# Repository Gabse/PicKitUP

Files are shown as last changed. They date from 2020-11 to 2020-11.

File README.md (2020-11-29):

# PicKitUP

AVR & SAM Adapter for Pickit4/SNAP 

 
=
Just a simple adapter board to connect most common AVR and SAM ICSP Ports to the Microchip Pickit4/SNAP Programmer

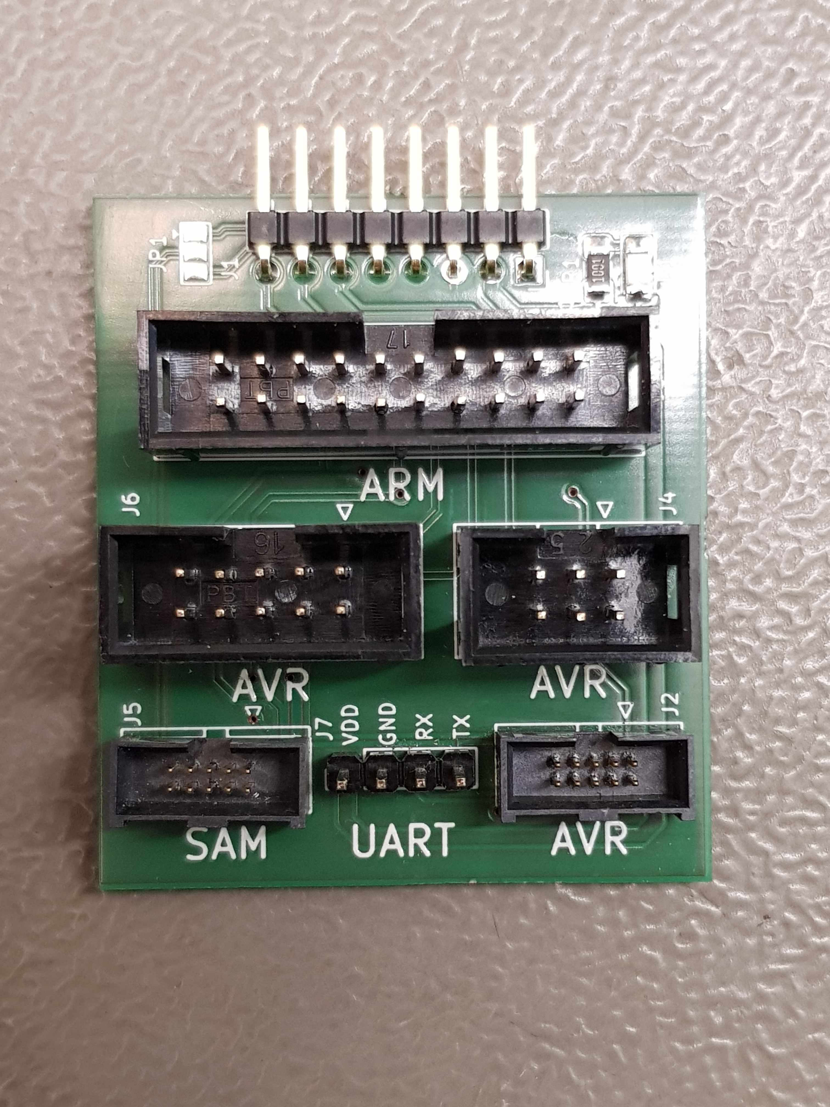
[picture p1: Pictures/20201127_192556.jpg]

=
If you Like this Project you can donate to the KiCad Project :

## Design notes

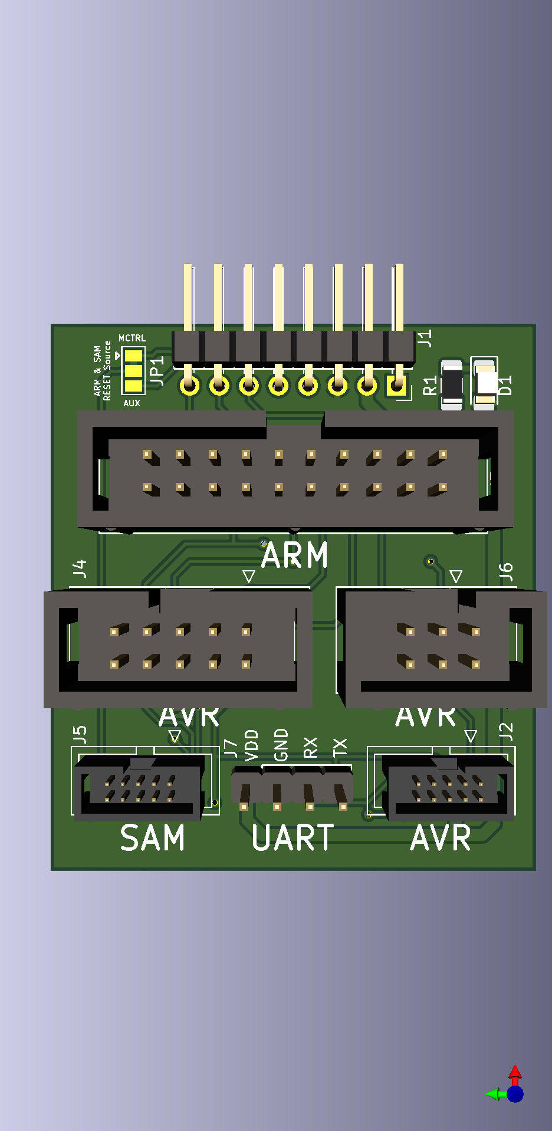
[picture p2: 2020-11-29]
Pictures/Render_Front.png

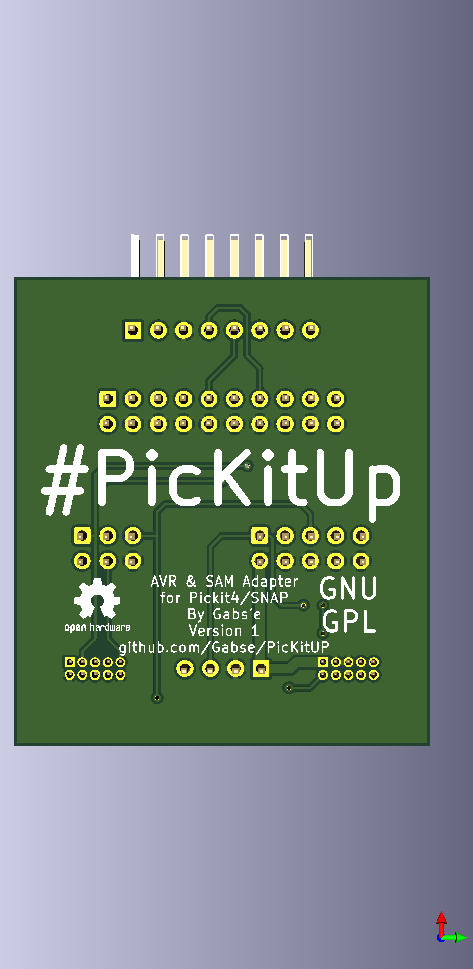
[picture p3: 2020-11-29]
Pictures/Render_Back.png

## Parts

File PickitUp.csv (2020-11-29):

Reference | Quantity | Value | Footprint | Datasheet | Manufacturer | Manufacturer Part Number | Order Code | Source
D1 | 1 | LED | LED_SMD:LED_1206_3216Metric_Pad1.42x1.75mm_HandSolder | https://www.we-online.de/katalog/datasheet/150120SS75000.pdf | Wurth Elektronik | 150120SS75000 | 2322087 | Farnell
J1 | 1 | PicKit_Connector | PickitUp:PinHeader_1x08_P2.54mm_Horizontal_Inverse | https://cdn.amphenol-icc.com/media/wysiwyg/files/drawing/68015.pdf | Amphenol FCI | 68016-208HLF | 2892394 | Farnell
J2 | 1 | AVR-JTAG-10 | PickitUp:SHF-105-01-L-D-TH | http://suddendocs.samtec.com/prints/shf-1xx-01-x-d-xx-xx-mkt.pdf | Samtec | SHF-105-01-L-D-TH | 2308450 | Farnell
J3 | 1 | ARM_JTAG_20 | Connector_IDC:IDC-Header_2x10_P2.54mm_Vertical | https://www.we-online.com/catalog/datasheet/61200621621.pdf | Wurth Elektronik | 61202021621 | 1642021 | Farnell
J4 | 1 | AVR-ISP-10 | Connector_IDC:IDC-Header_2x05_P2.54mm_Vertical | https://www.we-online.com/catalog/datasheet/61201021621.pdf | Wurth Elektronik | 61201021621 | 1642019 | Farnell
J5 | 1 | ARM_JTAG_10 | PickitUp:SHF-105-01-L-D-TH | http://suddendocs.samtec.com/prints/shf-1xx-01-x-d-xx-xx-mkt.pdf | Samtec | SHF-105-01-L-D-TH | 2308450 | Farnell
J6 | 1 | AVR-ISP-6 | Connector_IDC:IDC-Header_2x03_P2.54mm_Vertical | https://www.we-online.com/catalog/datasheet/61200621621.pdf | Wurth Elektronik | 61200621621 | 2356251 | Farnell
J7 | 1 | UART | Connector_PinHeader_2.54mm:PinHeader_1x04_P2.54mm_Vertical | https://www.we-online.com/catalog/datasheet/61300411121.pdf | Wurth Elektronik | 61300411121 | 2356155 | Farnell
JP1 | 1 | RESET | Jumper:SolderJumper-3_P1.3mm_Bridged12_Pad1.0x1.5mm | ~
R1 | 1 | 1k | Resistor_SMD:R_1206_3216Metric_Pad1.42x1.75mm_HandSolder | https://www.vishay.com/docs/20035/dcrcwe3.pdf | Vishay | CRCW12061K00FKEBC | 71-CRCW12061K00FKEBC | Farnell

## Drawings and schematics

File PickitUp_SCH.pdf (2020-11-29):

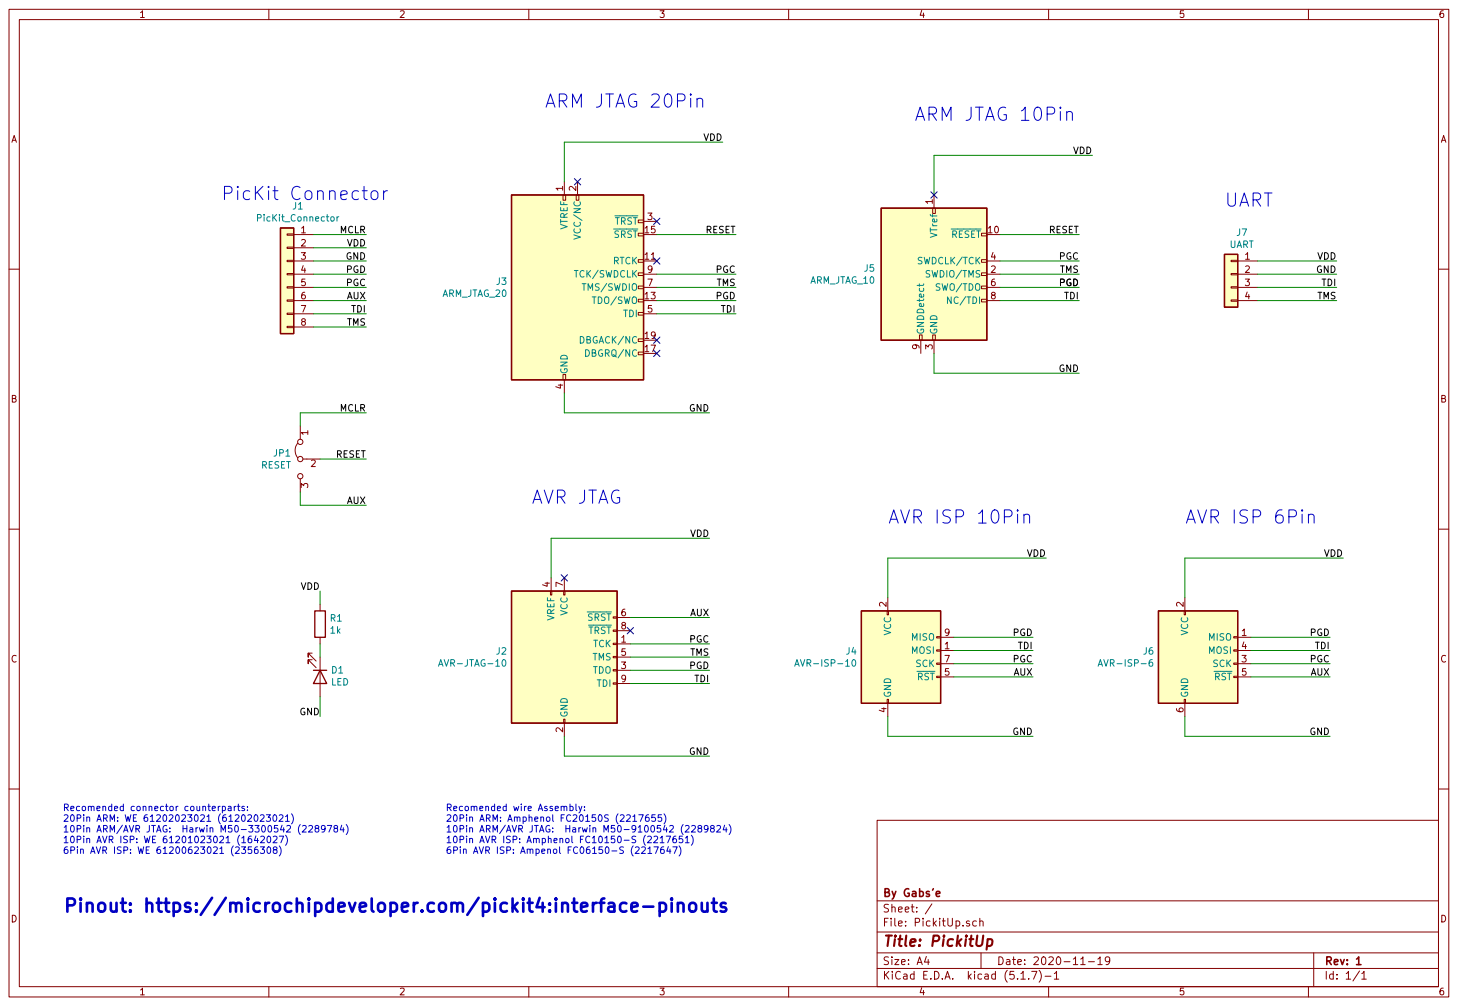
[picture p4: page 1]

1 RTCK 11 TDO/SWO 13 SRST 15 DBGRQ/NC 17 DBGACK/NC 19 VCC/NC
J7 UART VTREF

3 SWDCLK/TCK 4 SWO/TDO 6 NC/TDI 8 GNDDetect 9

4 TDI 5 TMS/SWDIO 7 TCK/SWDCLK 9

2 SCK 3 MOSI 4 RST 5 GND

Recomended connector counterparts:
20Pin ARM: WE 61202023021 (61202023021)
10Pin ARM/AVR JTAG: Harwin M50-3300542 (2289784)
10Pin AVR ISP: WE 61201023021 (1642027)
6Pin AVR ISP: WE 61200623021 (2356308)

Recomended wire Assembly:
20Pin ARM: Amphenol FC20150S (2217655)
10Pin ARM/AVR JTAG: Harwin M50-9100542 (2289824)
10Pin AVR ISP: Amphenol FC10150-S (2217651)
6Pin AVR ISP: Ampenol FC06150-S (2217647)

File: PickitUp.sch Sheet: / By Gabs'e

Pinout: https://microchipdeveloper.com/pickit4:interface-pinouts

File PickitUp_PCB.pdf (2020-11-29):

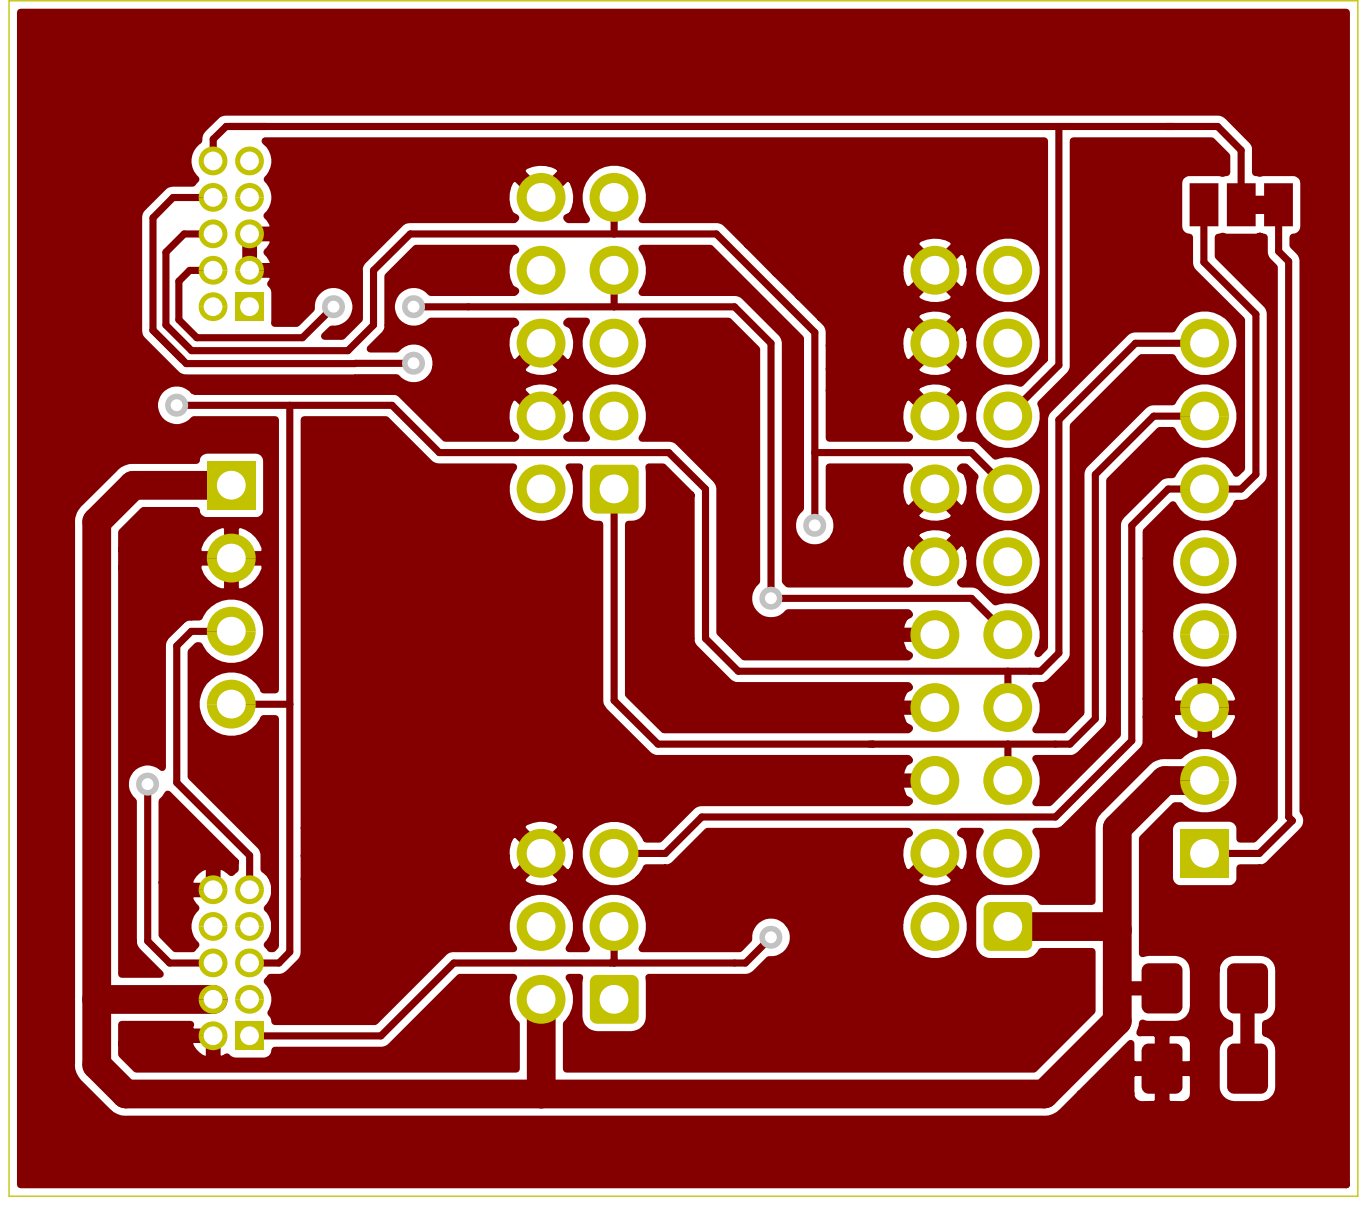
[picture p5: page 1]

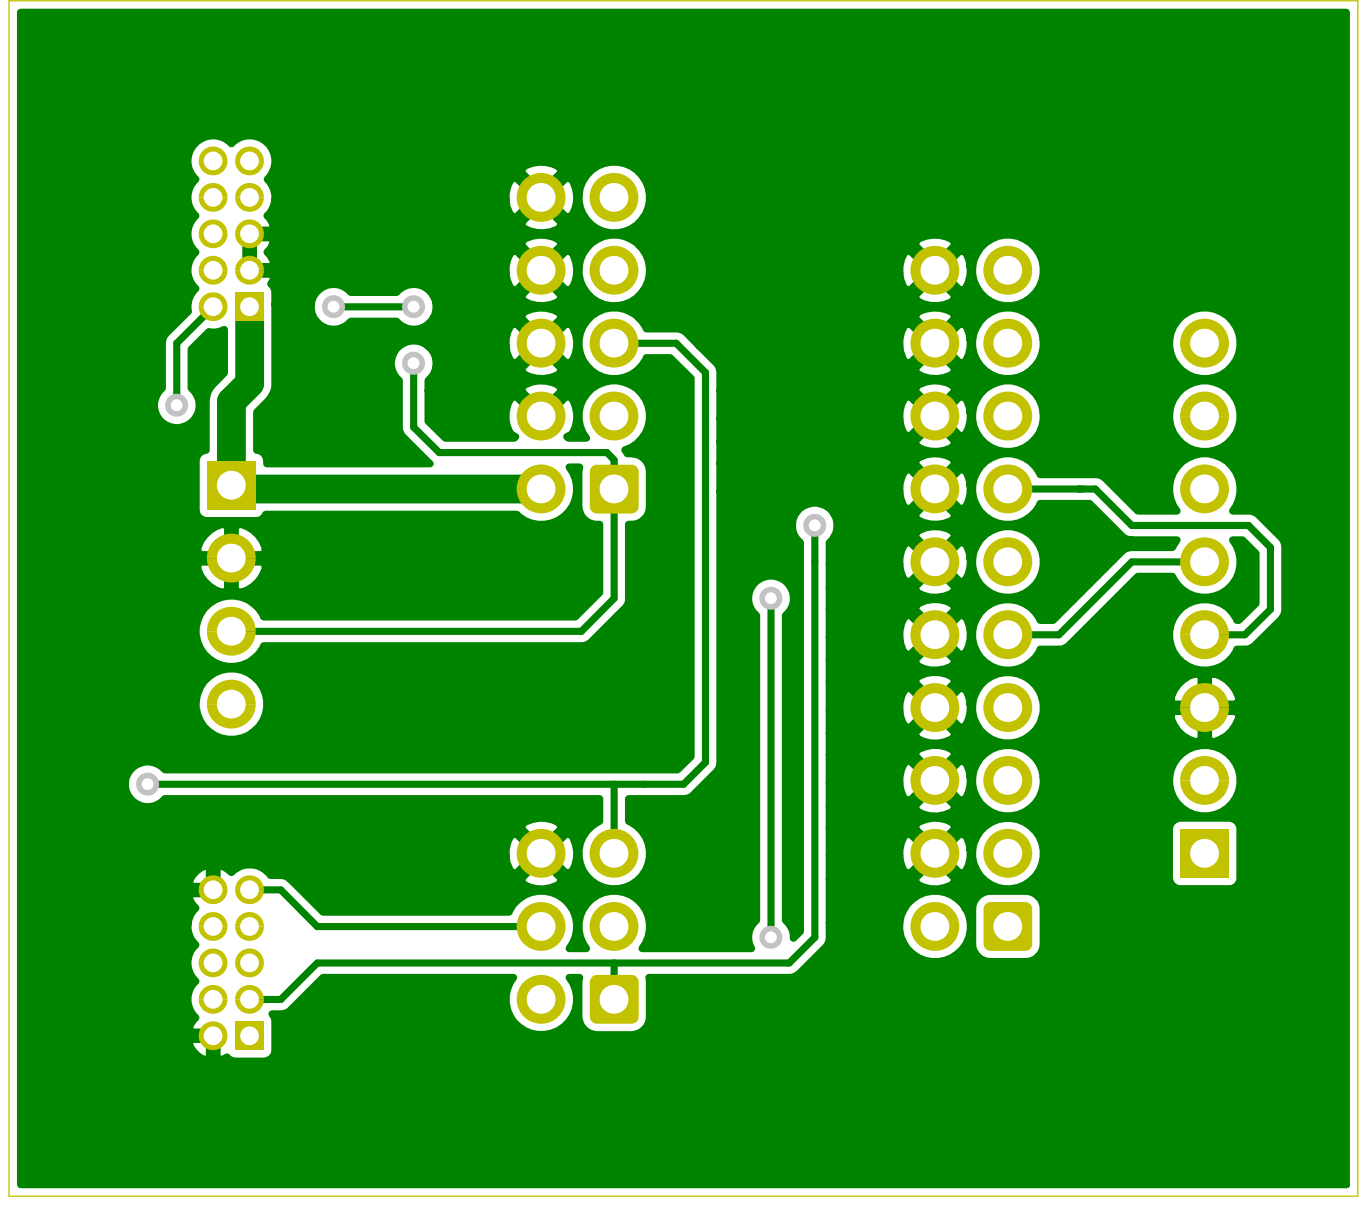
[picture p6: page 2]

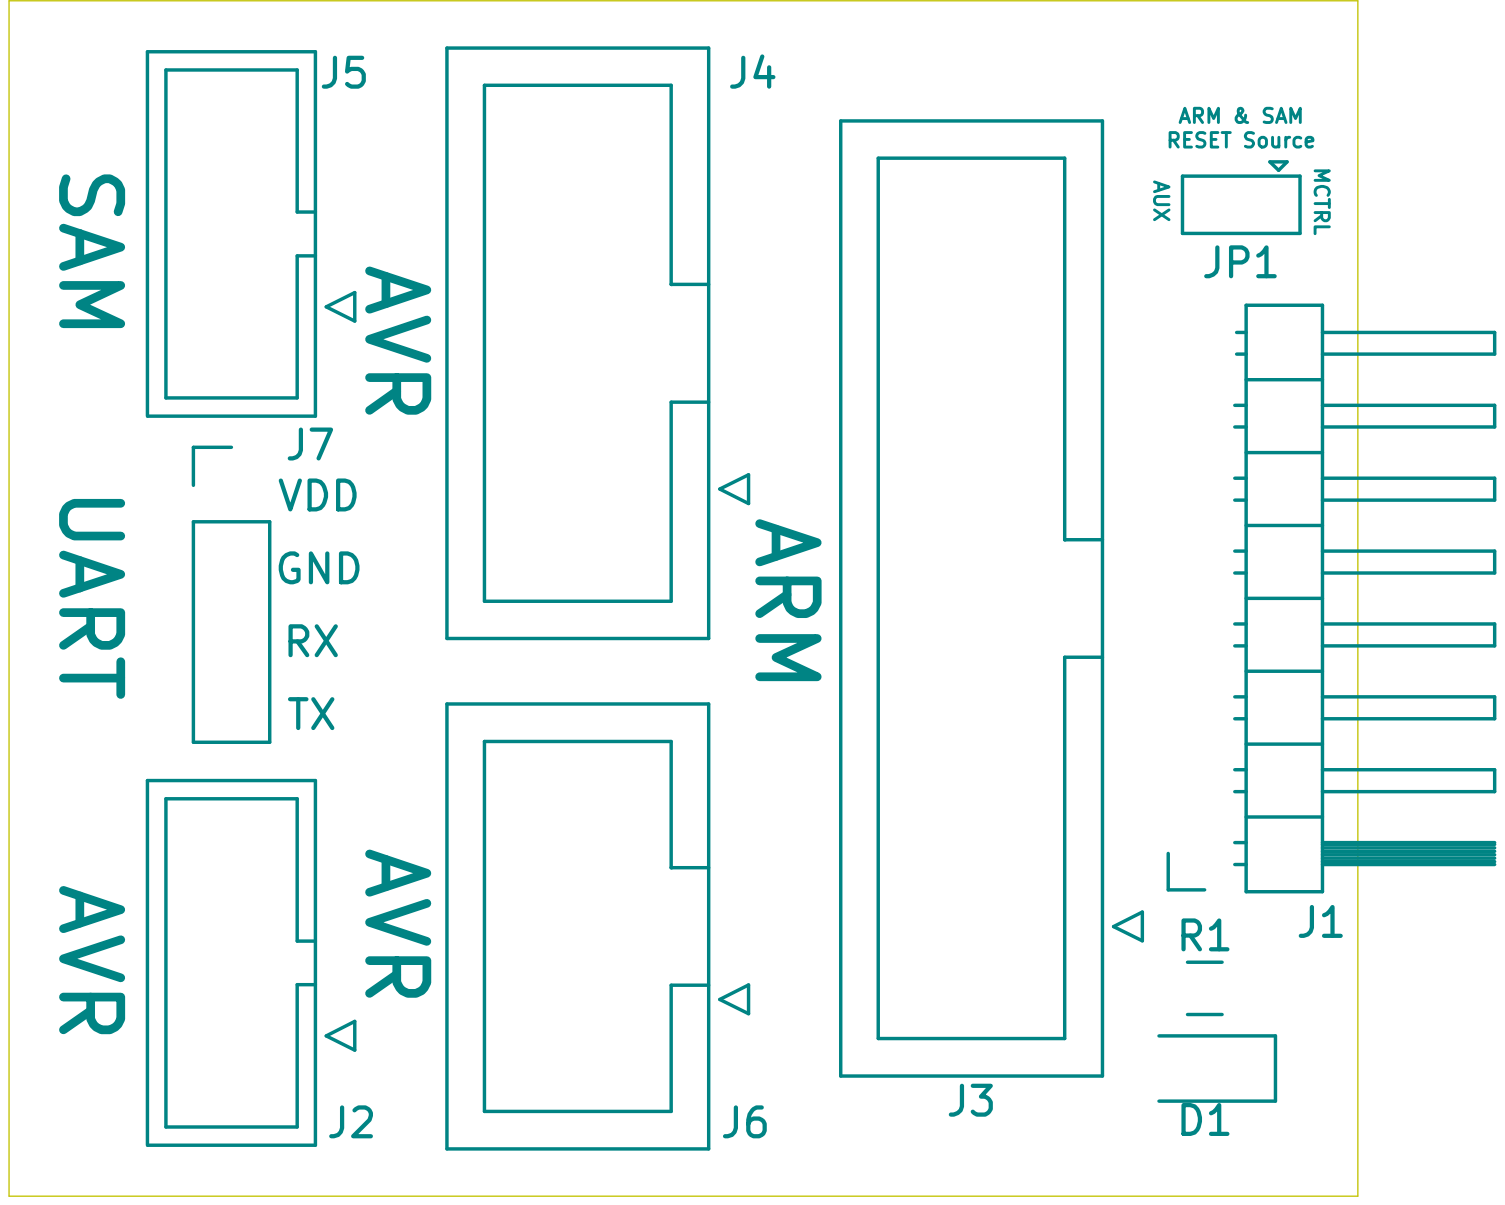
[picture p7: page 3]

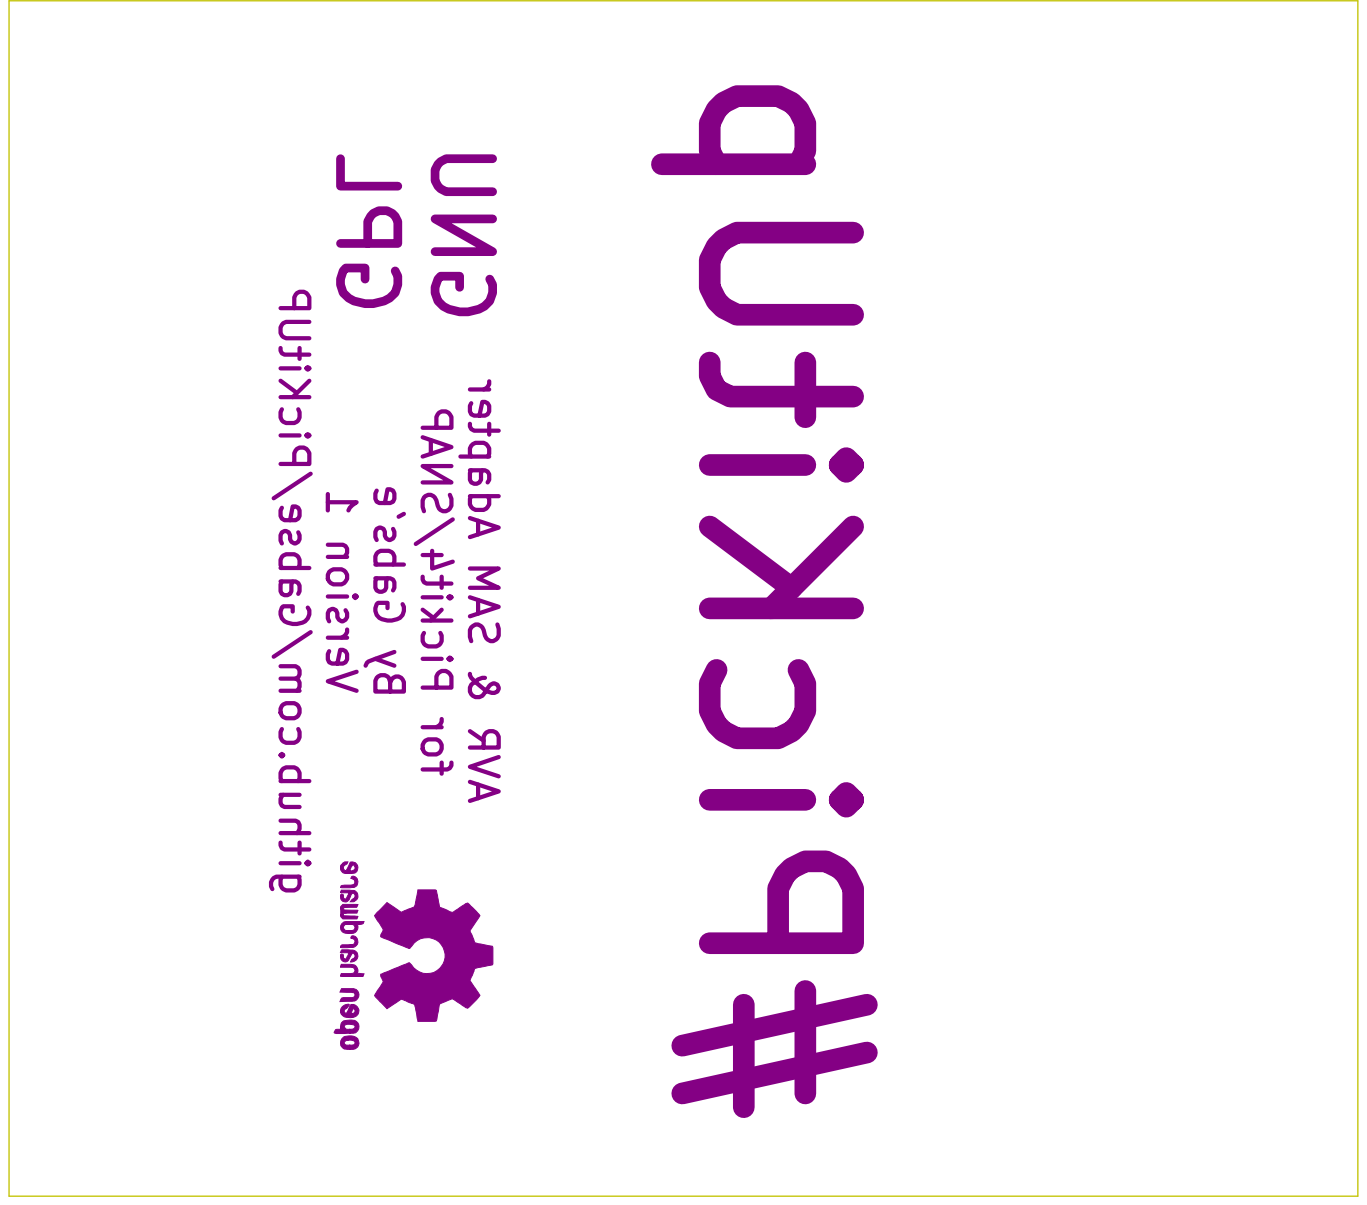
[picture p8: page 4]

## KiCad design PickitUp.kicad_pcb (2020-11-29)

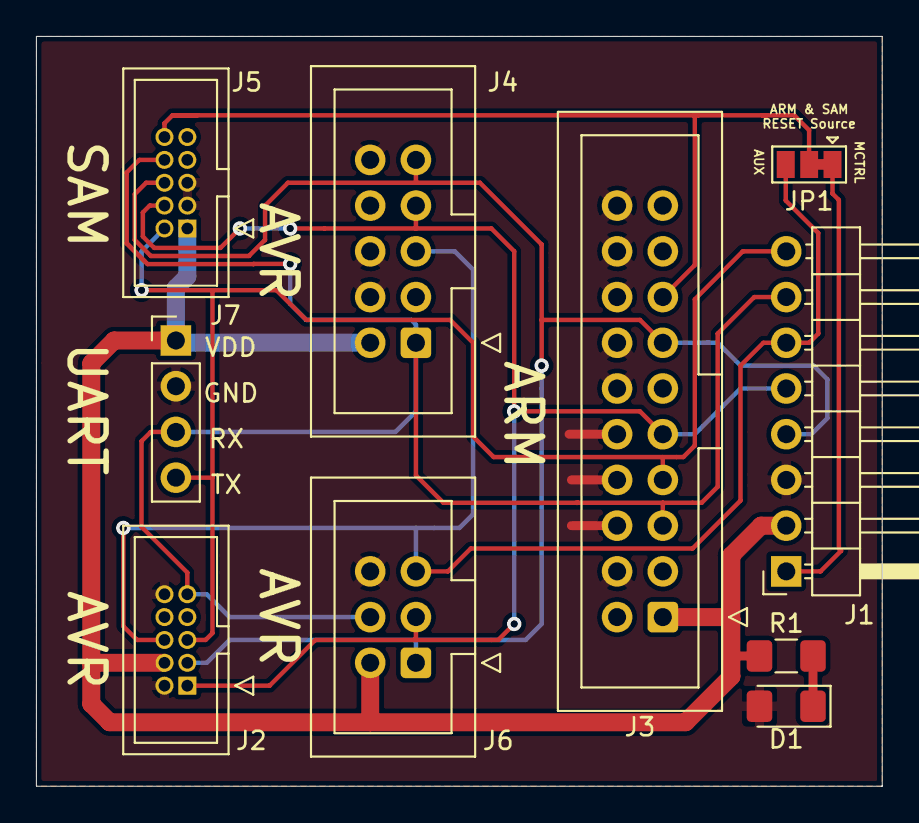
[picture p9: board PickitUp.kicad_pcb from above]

Board: 2 copper layers, 47.0 x 41.7 mm, 10 parts (0 on the bottom side), 10 nets.

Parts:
D1: LED; LED_1206_3216Metric_Pad1.42x1.75mm_HandSolder
J1: PicKit_Connector; PinHeader_1x08_P2.54mm_Horizontal_Inverse
J2: AVR-JTAG-10; SHF-105-01-L-D-TH
J3: ARM_JTAG_20; IDC-Header_2x10_P2.54mm_Vertical
J4: AVR-ISP-10; IDC-Header_2x05_P2.54mm_Vertical
J5: ARM_JTAG_10; SHF-105-01-L-D-TH
J6: AVR-ISP-6; IDC-Header_2x03_P2.54mm_Vertical
J7: UART; PinHeader_1x04_P2.54mm_Vertical
JP1: RESET; SolderJumper-3_P1.3mm_Bridged12_Pad1.0x1.5mm
R1: 1k; R_1206_3216Metric_Pad1.42x1.75mm_HandSolder

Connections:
/AUX: J1.6, J2.6, J4.5, J6.5, JP1.3
/GND: D1.2, J1.3, J2.2, J2.10, J3.4, J3.6, J3.8, J3.10, J3.12, J3.14, J3.16, J3.18, J3.20, J4.4, J4.6, J4.8, J4.10, J5.3, J5.5, J6.6, J7.2
/MCLR: J1.1, JP1.1
/PGC: J1.5, J2.1, J3.9, J4.7, J5.4, J6.3
/PGD: J1.4, J2.3, J3.13, J4.9, J5.6, J6.1
/RESET: J3.15, J5.10, JP1.2
/TDI: J1.7, J2.9, J3.5, J4.1, J5.8, J6.4, J7.3
/TMS: J1.8, J2.5, J3.7, J5.2, J7.4
/VDD: J1.2, J2.4, J3.1, J4.2, J5.1, J6.2, J7.1, R1.1
unnamed: D1.1, R1.2

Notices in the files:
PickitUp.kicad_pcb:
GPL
